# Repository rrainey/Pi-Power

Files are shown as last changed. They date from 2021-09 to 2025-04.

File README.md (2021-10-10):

# Pi-Power for DSKY-matic

This is an integrated power supply for the DSKY-matic.  It supplies 5VDC for the
Raspberry Pi, keyboard, and alarm modules. It also supplies either +3.3VDC or +7VDC for the Display module, depending on whether you are using the LED or EL variant of that module.

Takes power from a 9-24VDC power adapter. I am testing the DSKY-matic using a TRIAD model WS8U090-2000; 7VDC 2.0A.

PCB based on the original Pi-Power project from Tonymac32. I added a separate +3.3 VDC section to the original +5 VDC-only design.

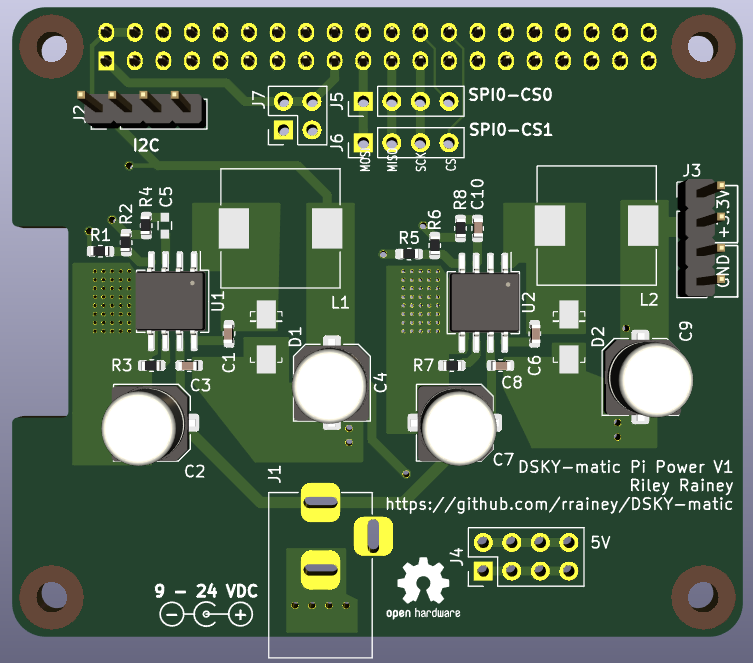
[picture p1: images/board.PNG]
board


## A Warning from the original author

Do not stick your fingers into this circuit while it's powering 
something you care about.  
Your fingers have a resistance value, and will change the feedback network regulating the output circuit, potentially 
causing a power surge.

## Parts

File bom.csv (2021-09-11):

Reference | Quantity | Value | Footprint | Datasheet
C1 C3 C6 C8 | 4 | 100nF | Capacitor_SMD:C_0603_1608Metric | ~
C10 | 1 | 220pF | Capacitor_SMD:C_0603_1608Metric | ~
C2 C7 | 2 | 10uF | Capacitor_SMD:C_Elec_6.3x5.8 | ~
C4 C9 | 2 | 22uF | Capacitor_SMD:C_Elec_6.3x5.8 | ~
C5 | 1 | 150pF | Capacitors_SMD:C_0603 | ~
D1 D2 | 2 | D_Schottky | digikey-footprints:DO-214AC | ~
J1 | 1 | Barrel_Jack_Switch | Connectors:BARREL_JACK | ~
J3 J2 | 2 | Conn_01x04 | Connector_PinHeader_2.54mm:PinHeader_1x04_P2.54mm_Vertical | ~
J4 | 1 | Conn_02x04_Odd_Even | Pin_Headers:Pin_Header_Straight_2x04_Pitch2.54mm | ~
J5 J6 | 2 | Conn_01x04 | Pin_Headers:Pin_Header_Straight_1x04_Pitch2.54mm | ~
J7 | 1 | Conn_02x02_Odd_Even | Pin_Headers:Pin_Header_Straight_2x02_Pitch2.54mm | ~
L1 | 1 | 22uH | Inductor_SMD:L_10.4x10.4_H4.8 | ~
L2 | 1 | 10uH | Inductor_SMD:L_10.4x10.4_H4.8 | ~
MK1 MK2 MK3 MK4 | 4 | M2.5 | MountingHole:MountingHole_2.7mm_M2.5
P1 | 1 | Conn_02x20_Odd_Even | Connector_PinSocket_2.54mm:PinSocket_2x20_P2.54mm_Vertical
R1 | 1 | 210k | Resistor_SMD:R_0603_1608Metric | ~
R2 R6 | 2 | 40.2k | Resistor_SMD:R_0603_1608Metric | ~
R4 R3 | 2 | 100k | Resistor_SMD:R_0603_1608Metric | ~
R5 | 1 | 124K | Resistor_SMD:R_0603_1608Metric | ~
R7 | 1 | 200k | Resistor_SMD:R_0603_1608Metric | ~
R8 | 1 | 68.1k | Resistor_SMD:R_0603_1608Metric | ~
U1 U2 | 2 | MP1584 | Package_SO:SO-8_5.3x6.2mm_P1.27mm

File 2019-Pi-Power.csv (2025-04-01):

Reference | Qty | Value | DNP | Exclude from BOM | Footprint | MANUFACTURER | MPN | Description
C1,C3,C6,C8 | 4 | 100nF |  |  | Capacitor_SMD:C_0603_1608Metric | Samsung | CL10B104KB8NNNC | 0.1 µF ±10% 50V Ceramic Capacitor X7R 0603 (1608 Metric)
C2,C7 | 2 | 10uF |  |  | Capacitor_SMD:C_Elec_6.3x5.8 | Panasonic | EEE-1HA100SP | CAP ALUM 10UF 20% 50V SMD
C4,C9 | 2 | 22uF |  |  | Capacitor_SMD:C_Elec_6.3x5.8 | Panasonic | EEH-ZA1H220P | CAP ALUM HYBRID 22UF 20% 50V SMD
C5 | 1 | 150pF |  |  | Capacitors_SMD:C_0603 | Samsung | CL10B151KB8NNNC | 150 pF ±10% 50V Ceramic Capacitor X7R 0603 (1608 Metric)
C10 | 1 | 220pF |  |  | Capacitor_SMD:C_0603_1608Metric | Samsung | CL10B221KB8NFNC | 220 pF ±10% 50V Ceramic Capacitor X7R 0603 (1608 Metric)
D1,D2 | 2 | D_Schottky |  |  | digikey-footprints:DO-214AC | Diodes Incorporated | B340A-13-F
J1 | 1 | Barrel_Jack_Switch |  |  | Connectors:BARREL_JACK | Same Sky (formerly CUI) | PJ-002AH
J2 | 1 | 1719710004 | DNP |  | Pi-Power:MOLEX_1719710004 | Molex | 1719710004
J3 | 1 | Conn_01x04 |  |  | Connector_PinHeader_2.54mm:PinHeader_1x04_P2.54mm_Vertical
J4 | 1 | Conn_02x04_Odd_Even | DNP |  | Pin_Headers:Pin_Header_Straight_2x04_Pitch2.54mm
J5,J6 | 2 | Conn_01x04 | DNP |  | Pin_Headers:Pin_Header_Straight_1x04_Pitch2.54mm
J7 | 1 | Conn_02x02_Odd_Even | DNP |  | Pin_Headers:Pin_Header_Straight_2x02_Pitch2.54mm
L1 | 1 | 22uH |  |  | Inductor_SMD:L_10.4x10.4_H4.8 | Würth Elektronik | 7447714220
L2 | 1 | 10uH |  |  | Inductor_SMD:L_10.4x10.4_H4.8 | Würth Elektronik | 744065100
MK1,MK2,MK3,MK4 | 4 | M2.5 |  | Excluded from BOM | MountingHole:MountingHole_2.7mm_M2.5
P1 | 1 | Conn_02x20_Odd_Even |  |  | Connector_PinSocket_2.54mm:PinSocket_2x20_P2.54mm_Vertical
R1 | 1 | 210k |  |  | Resistor_SMD:R_0603_1608Metric | Panasonic | ERJ-H3EF2103V | RES 210K OHM 1% 1/8W 0603
R2,R6 | 2 | 40.2k |  |  | Resistor_SMD:R_0603_1608Metric | Panasonic | ERA-3VEB4022V | RES 40.2K OHM 0.1% 1/8W 0603
R3,R4 | 2 | 100k |  |  | Resistor_SMD:R_0603_1608Metric | Panasonic | ERJ-H3EF1003V | RES 100K OHM 1% 1/8W 0603
R5 | 1 | 124K |  |  | Resistor_SMD:R_0603_1608Metric | KOA | RN73R1JTTD1243D25 | RES 124K OHM 0.5% 1/10W 0603
R7 | 1 | 200k |  |  | Resistor_SMD:R_0603_1608Metric | Panasonic | ERJ-H3EF2003V | RES 200K OHM 1% 1/8W 0603
R8 | 1 | 68.1k |  |  | Resistor_SMD:R_0603_1608Metric | Vishay | MCT06030C6812FP500 | RES 68.1K OHM 1% 1/10W 0603
U1,U2 | 2 | MP1584 |  |  | Package_SO:SO-8_5.3x6.2mm_P1.27mm | Monolithic Power | MP1584EN-LF-Z | Buck Switching Regulator IC Positive Adjustable 0.8V 1 Output 3A 8-SOIC (0.154", 3.90mm Width) Exposed Pad

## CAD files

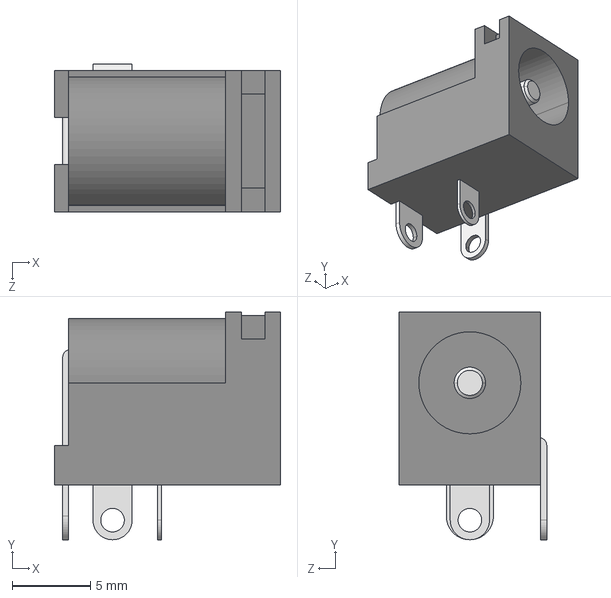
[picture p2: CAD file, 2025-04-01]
models/Same_Sky_PJ-002AH.step
14.4 x 14.5 x 9.40 mm

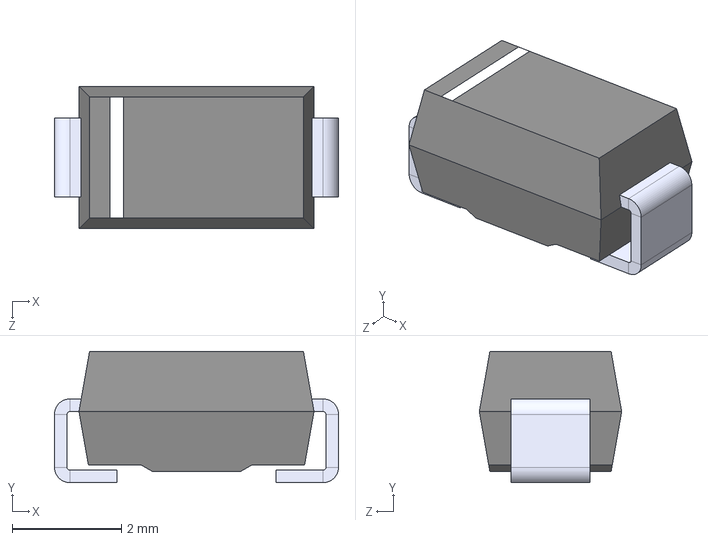
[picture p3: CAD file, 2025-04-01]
models/B340A-13-F.step
5.20 x 2.40 x 2.60 mm

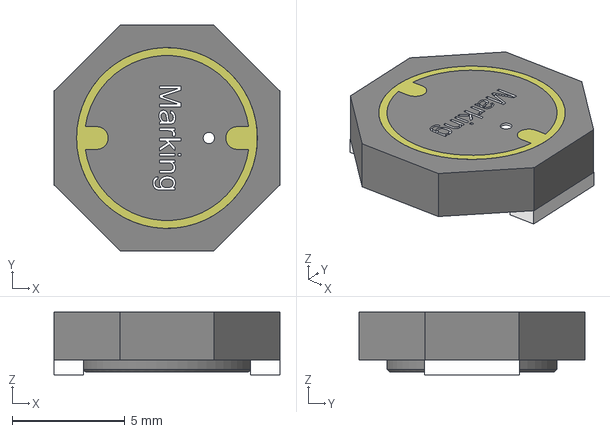
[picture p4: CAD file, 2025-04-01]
models/744065001_Download_STP_WE-TPC-1028_rev1.stp
10.0 x 10.00 x 2.78 mm

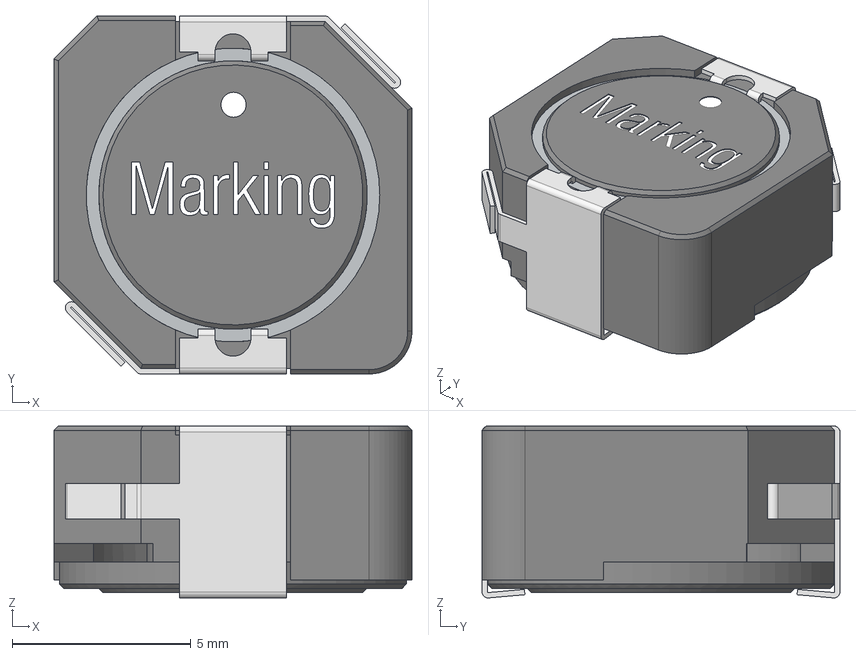
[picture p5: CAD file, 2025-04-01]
models/7447714015_Download_7447714xx.stp_rev1.stp
10.0 x 10.0 x 4.80 mm
shielding ring
core
base x 2
glue

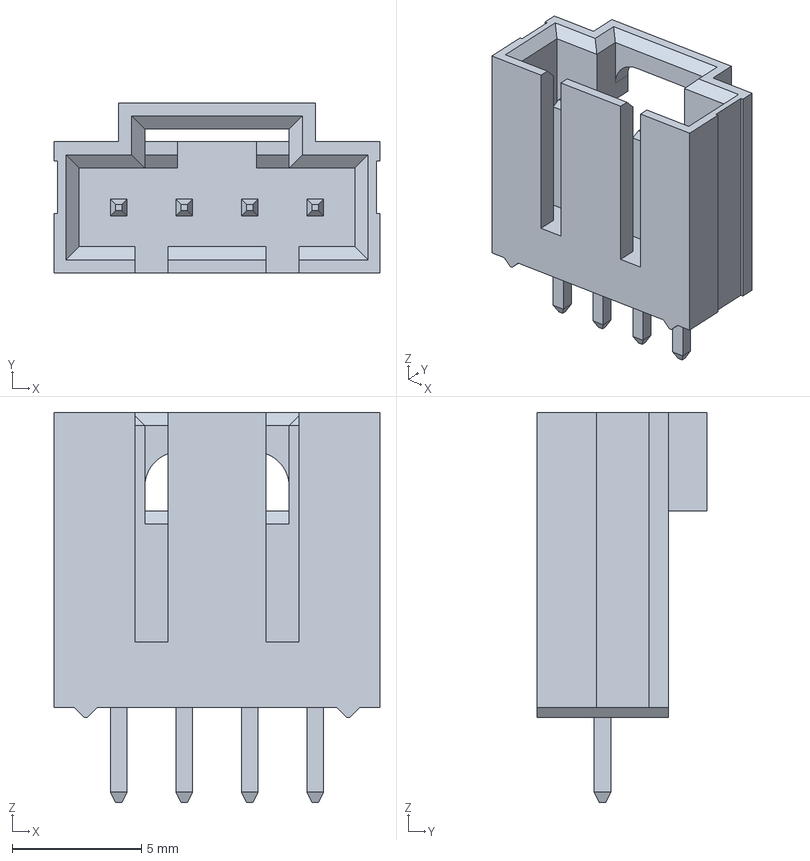
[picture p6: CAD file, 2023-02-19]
models/1719710004.step
12.6 x 6.60 x 15.1 mm

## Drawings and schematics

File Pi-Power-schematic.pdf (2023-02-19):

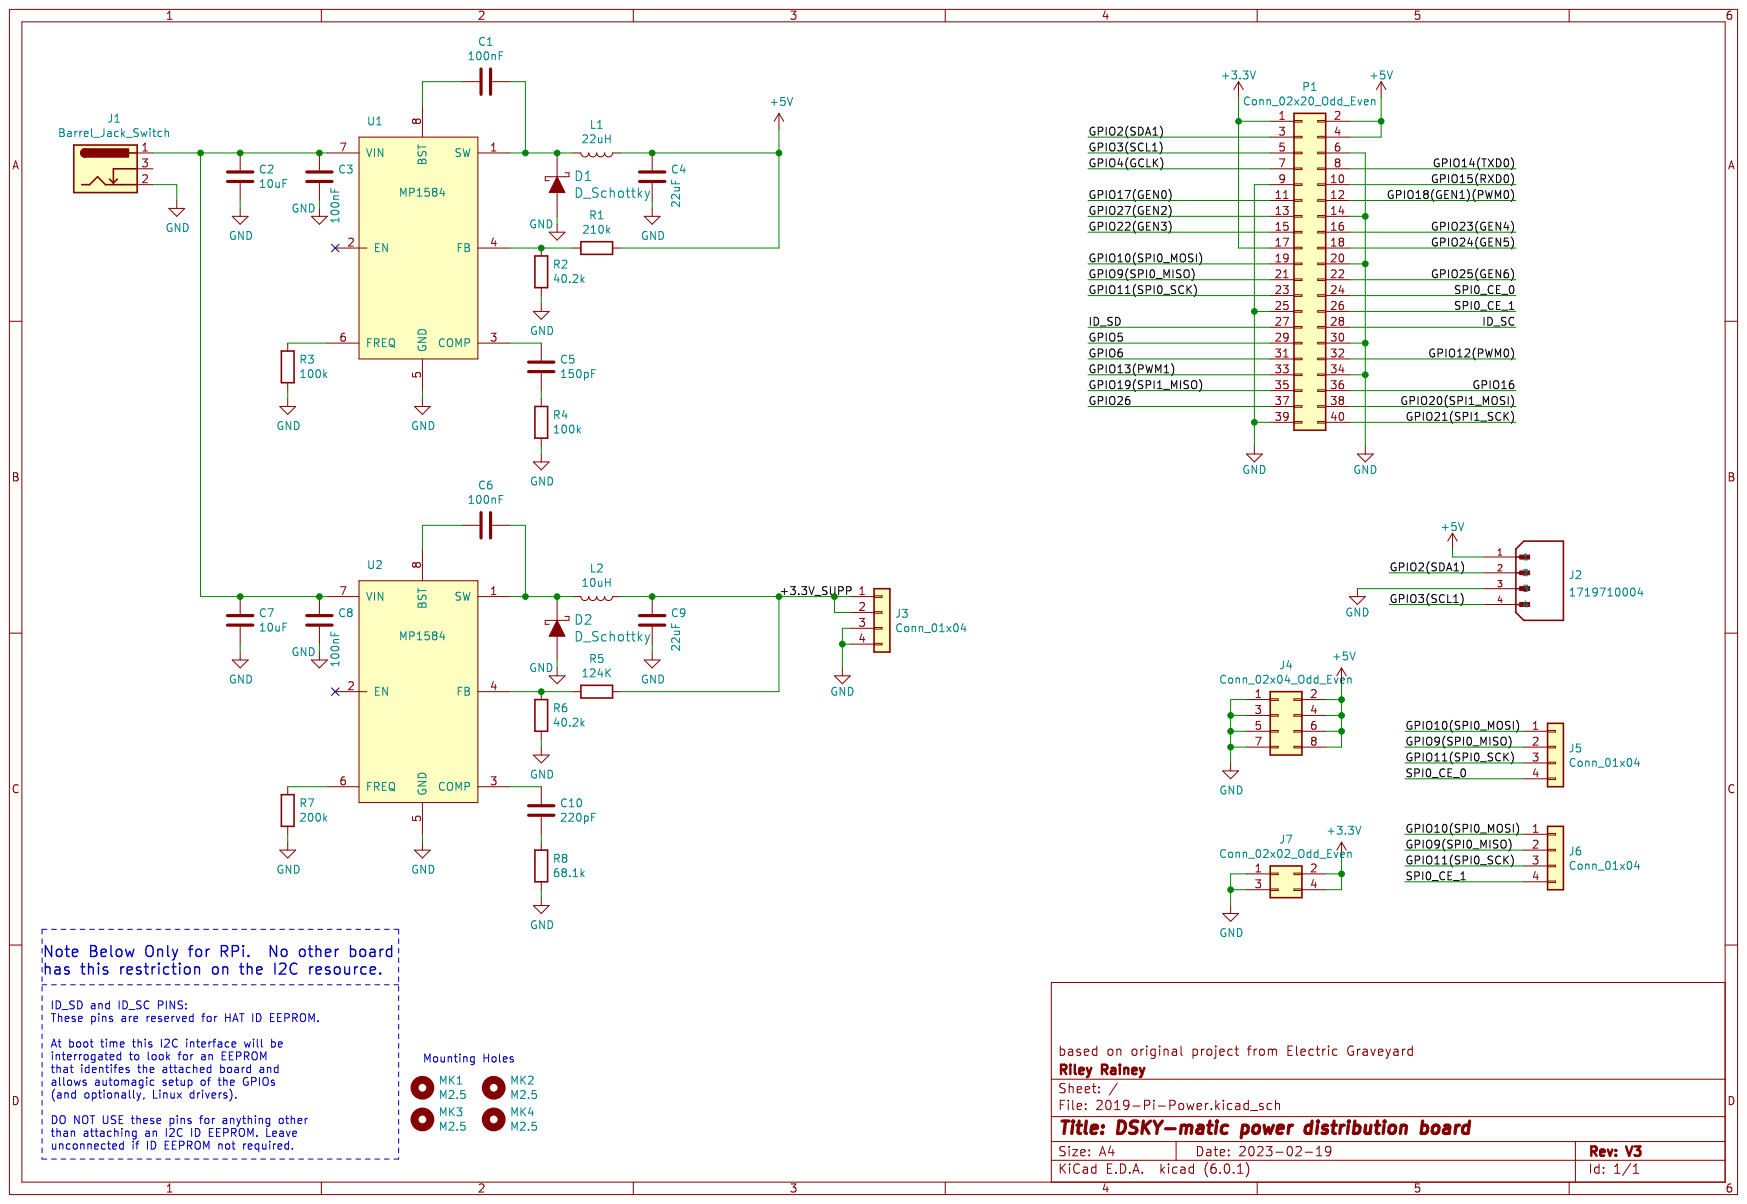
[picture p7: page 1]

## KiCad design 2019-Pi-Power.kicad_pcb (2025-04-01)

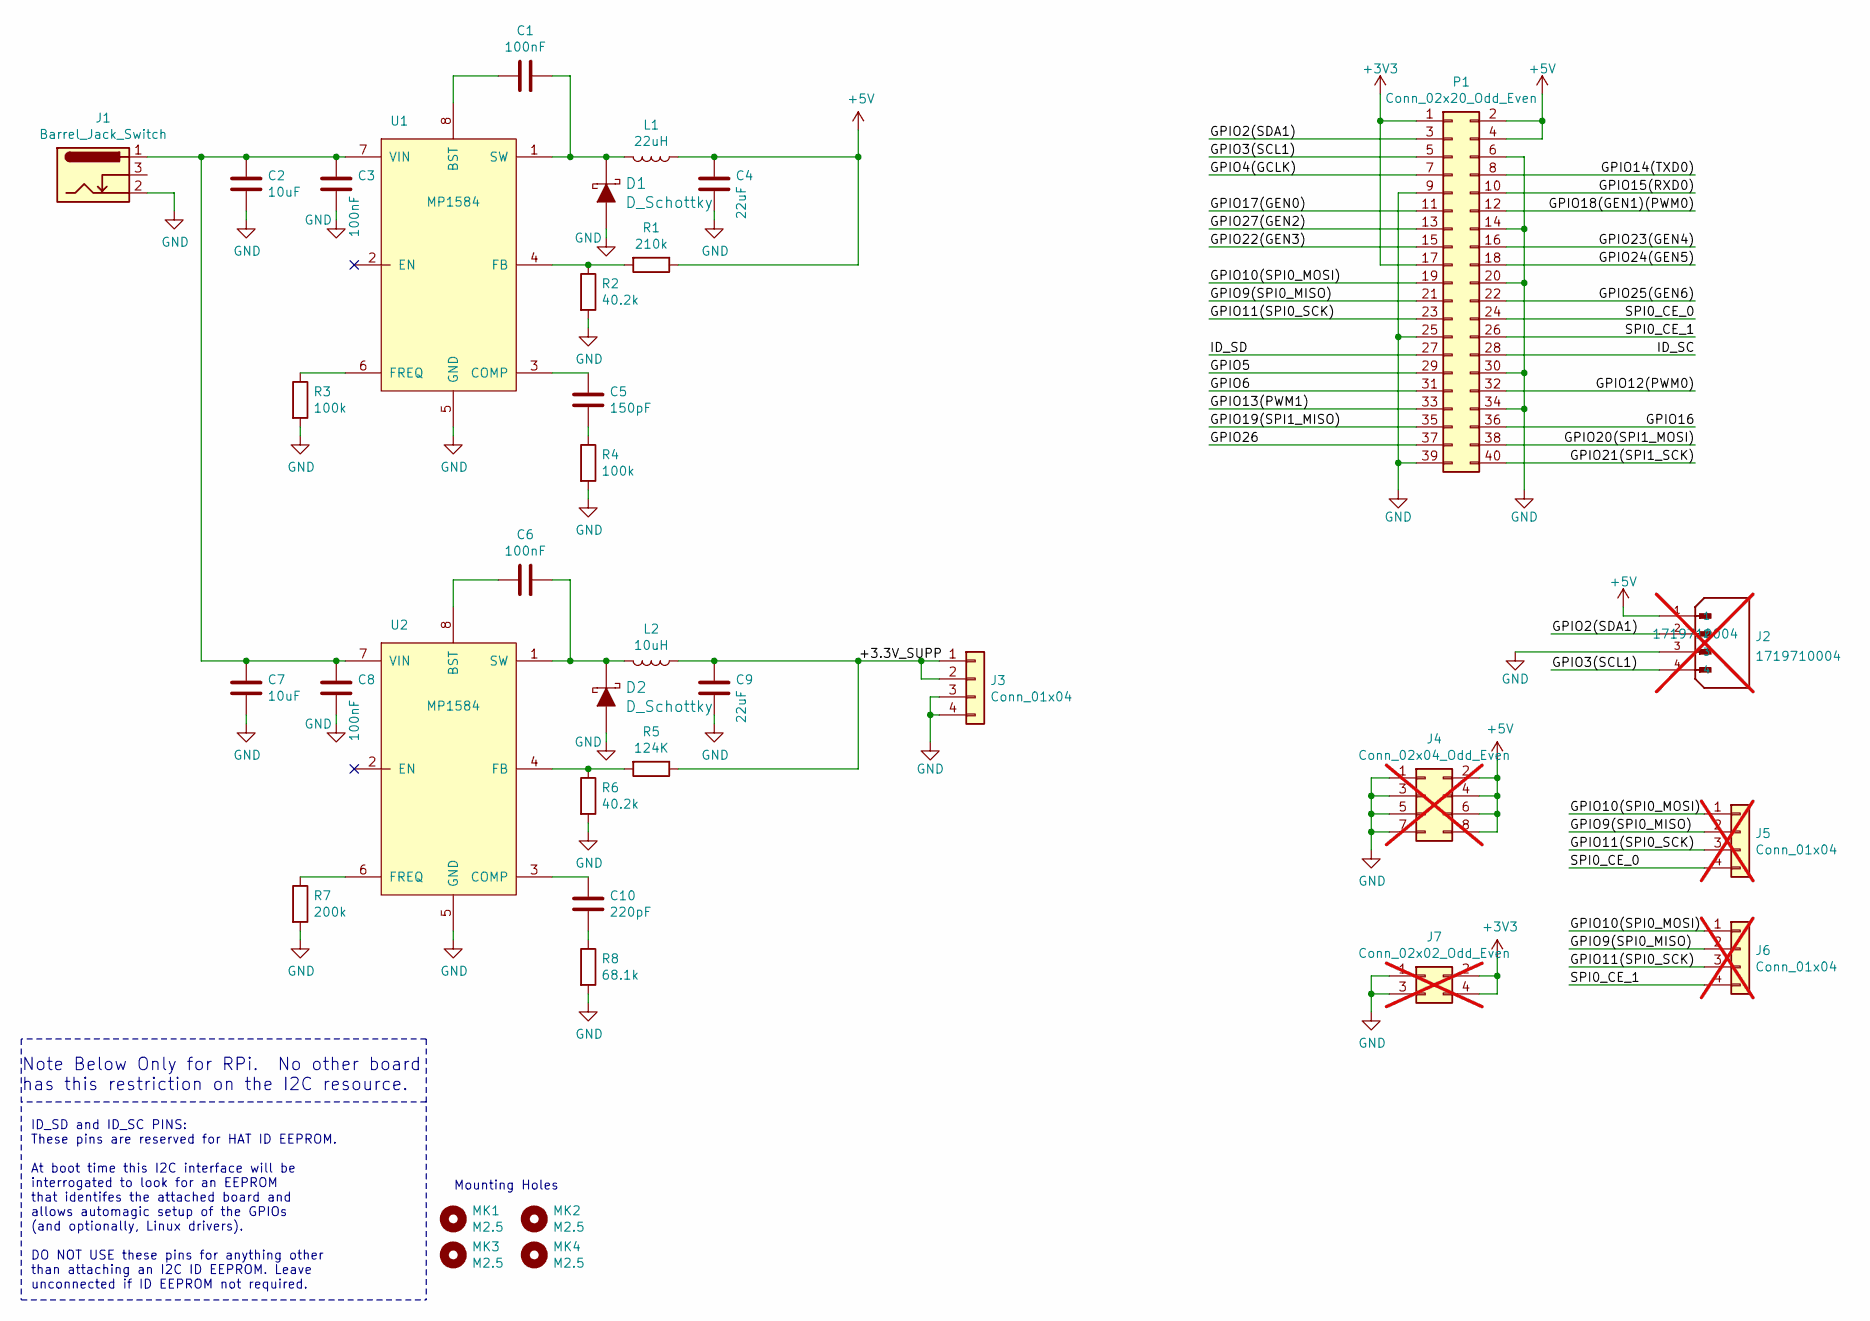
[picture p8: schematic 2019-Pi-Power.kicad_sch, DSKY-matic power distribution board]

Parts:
C1, C3, C6, C8: 100nF; C_0603_1608Metric; MPN CL10B104KB8NNNC
C2, C7: 10uF; C_Elec_6.3x5.8; MPN EEE-1HA100SP
C4, C9: 22uF; C_Elec_6.3x5.8; MPN EEH-ZA1H220P
C5: 150pF; C_0603; MPN CL10B151KB8NNNC
C10: 220pF; C_0603_1608Metric; MPN CL10B221KB8NFNC
D1, D2: D_Schottky; DO-214AC; MPN B340A-13-F
J1: Barrel_Jack_Switch; BARREL_JACK; MPN PJ-002AH
J2: 1719710004; MOLEX_1719710004; PARTREV C1; not fitted
J3: Conn_01x04; PinHeader_1x04_P2.54mm_Vertical
J4: Conn_02x04_Odd_Even; Pin_Header_Straight_2x04_Pitch2.54mm; not fitted
J5, J6: Conn_01x04; Pin_Header_Straight_1x04_Pitch2.54mm; not fitted
J7: Conn_02x02_Odd_Even; Pin_Header_Straight_2x02_Pitch2.54mm; not fitted
L1: 22uH; L_10.4x10.4_H4.8; MPN 7447714220
L2: 10uH; L_10.4x10.4_H4.8; MPN 744065100
MK1, MK2, MK3, MK4: M2.5; MountingHole_2.7mm_M2.5
P1: Conn_02x20_Odd_Even; PinSocket_2x20_P2.54mm_Vertical
R1: 210k; R_0603_1608Metric; MPN ERJ-H3EF2103V
R2, R6: 40.2k; R_0603_1608Metric; MPN ERA-3VEB4022V
R3, R4: 100k; R_0603_1608Metric; MPN ERJ-H3EF1003V
R5: 124K; R_0603_1608Metric; MPN RN73R1JTTD1243D25
R7: 200k; R_0603_1608Metric; MPN ERJ-H3EF2003V
R8: 68.1k; R_0603_1608Metric; MPN MCT06030C6812FP500
U1, U2: MP1584; SO-8_5.3x6.2mm_P1.27mm; MPN MP1584EN-LF-Z

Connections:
+3V3: J7.2, J7.4, P1.1, P1.17
+5V: C4.1, J2.1, J4.2, J4.4, J4.6, J4.8, L1.1, P1.2, P1.4, R1.1
/+3.3V_SUPP: C9.1, J3.1, J3.2, L2.1, R5.1
/GPIO2(SDA1): J2.2, P1.3
/GPIO3(SCL1): J2.4, P1.5
/GPIO4(GCLK): P1.7
/GPIO5: P1.29
/GPIO6: P1.31
/GPIO9(SPI0_MISO): J5.2, J6.2, P1.21
/GPIO10(SPI0_MOSI): J5.1, J6.1, P1.19
/GPIO11(SPI0_SCK): J5.3, J6.3, P1.23
/GPIO12(PWM0): P1.32
/GPIO13(PWM1): P1.33
/GPIO14(TXD0): P1.8
/GPIO15(RXD0): P1.10
/GPIO16: P1.36
/GPIO17(GEN0): P1.11
/GPIO18(GEN1)(PWM0): P1.12
/GPIO19(SPI1_MISO): P1.35
/GPIO20(SPI1_MOSI): P1.38
/GPIO21(SPI1_SCK): P1.40
/GPIO22(GEN3): P1.15
/GPIO23(GEN4): P1.16
/GPIO24(GEN5): P1.18
/GPIO25(GEN6): P1.22
/GPIO26: P1.37
/GPIO27(GEN2): P1.13
/ID_SC: P1.28
/ID_SD: P1.27
/SPI0_CE_0: J5.4, P1.24
/SPI0_CE_1: J6.4, P1.26
GND: C2.2, C3.2, C4.2, C7.2, C8.2, C9.2, D1.A, D2.A, J1.2, J2.3, J3.3, J3.4, J4.1, J4.3, J4.5, J4.7, J7.1, J7.3, P1.6, P1.9, P1.14, P1.20, P1.25, P1.30, P1.34, P1.39, R2.2, R3.2, R4.2, R6.2, R7.2, R8.2, U1.5 (GND), U2.5 (GND)
unnamed: C5.2, R4.1
unnamed: C10.2, R8.1
unnamed: C1.2, U1.8 (BST)
unnamed: C5.1, U1.3 (COMP)
unnamed: R1.2, R2.1, U1.4 (FB)
unnamed: R3.1, U1.6 (FREQ)
unnamed: C1.1, D1.K, L1.2, U1.1 (SW)
unnamed: C2.1, C3.1, C7.1, C8.1, J1.1, U1.7 (VIN), U2.7 (VIN)
unnamed: C6.2, U2.8 (BST)
unnamed: C10.1, U2.3 (COMP)
unnamed: R5.2, R6.1, U2.4 (FB)
unnamed: R7.1, U2.6 (FREQ)
unnamed: C6.1, D2.K, L2.2, U2.1 (SW)

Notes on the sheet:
Mounting Holes
Note Below Only for RPi. No other board has this restriction on the I2C resource.
ID_SD and ID_SC PINS: These pins are reserved for HAT ID EEPROM. At boot time this I2C interface will be interrogated to look for an EEPROM that identifes the attached board and allows automagic setup of the GPIOs (and optionally, Linux drivers). DO NOT USE these pins for anything other than attach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

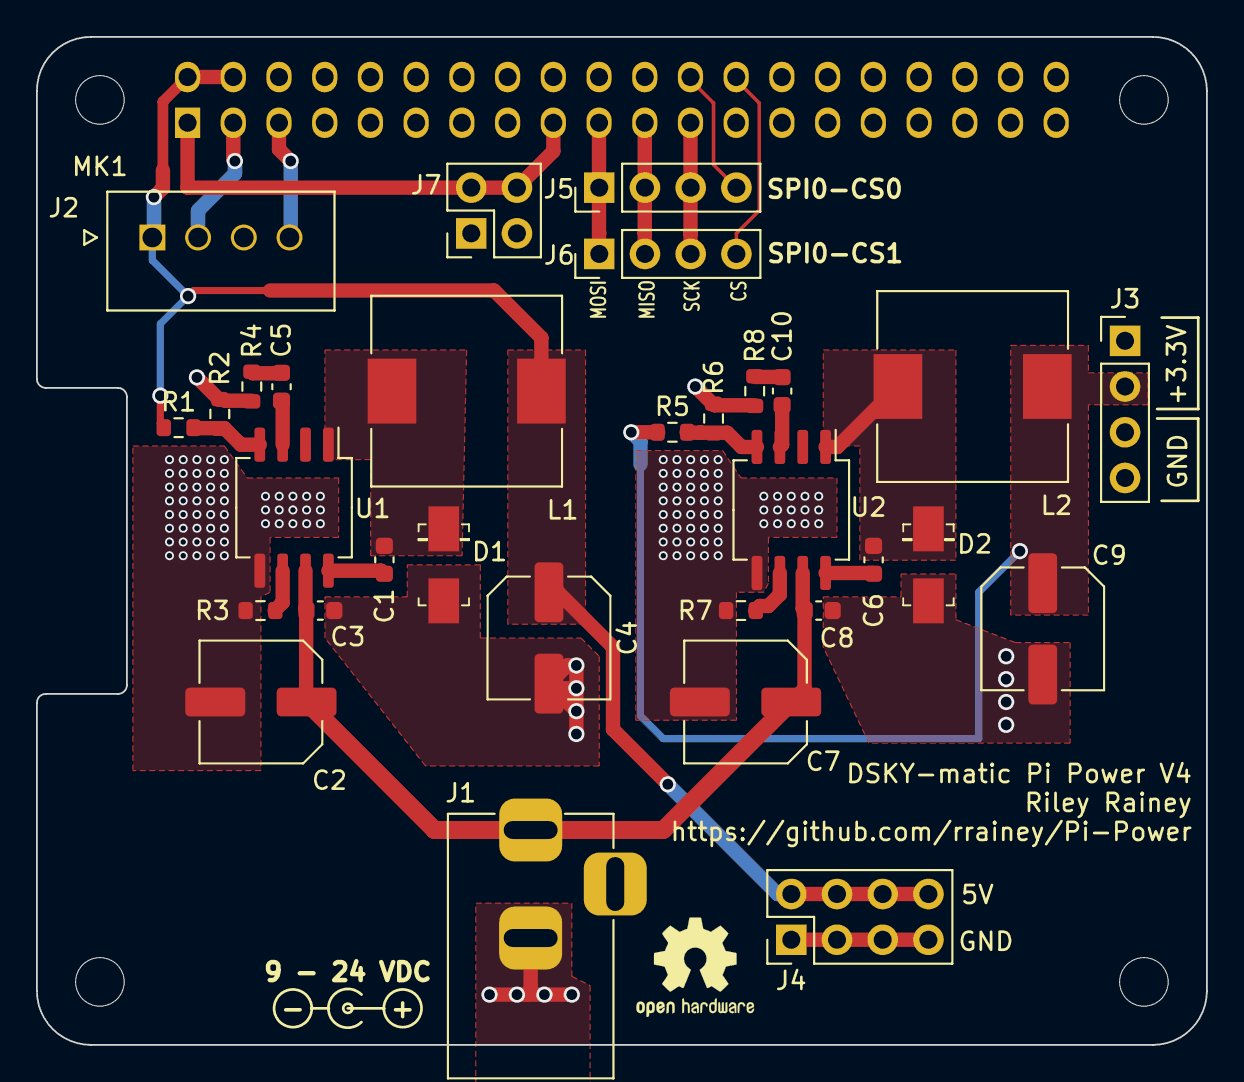
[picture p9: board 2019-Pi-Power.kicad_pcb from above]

Board: 2 copper layers, 65.0 x 56.0 mm, 36 parts (1 on the bottom side), 24 nets.

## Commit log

2021-09-11 V1 of DSKY-matic variant of this board
    [2019-Pi-Power-B.Cu.gbl, 2019-Pi-Power-B.Mask.gbs, 2019-Pi-Power-B_Cu.gbl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]
2021-10-10 V2 board: fix issue with + power input on back of board
    [2019-Pi-Power.kicad_pcb, 2019-Pi-Power.sch]
2021-10-10 Update README to describe TRIAD power supply
2023-02-19 V3 Board - adds Molex I2C interconnect
    [1719710004.step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]
2025-04-01 V4 PCB
    [2019-Pi-Power-B_Cu.gbl, 2019-Pi-Power-B_Mask.gbs, 2019-Pi-Power-B_Paste.gbp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]
